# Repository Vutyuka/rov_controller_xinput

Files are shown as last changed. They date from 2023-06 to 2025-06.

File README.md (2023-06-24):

# ROV Controller firmware

ROV Controller firmware, emulating an XBOX gamepad,
using XInput. An underwater casing will be used,
so all buttons are two-state push buttons.
Buttons represent Hall-effect sensors in the hardware.

Basic controller functionality, easy to add and remove buttons:

1. Add/remove pinout definition for pin.
2. Add/remove pin to button_table.
3. Change button_num.

Using Left Joystick with 4 push buttons. 
Joystick position/speed can be toggled by push button.

Any number of discrete speeds can be added to motor_speed_t.

Tested on Pro Micro(has to be flashed as Leonardo).

**To flash:** Press reset just as the IDE shows "Uploading" promt
IT WILL BRICK THE DEVICE IF THIS IS NOT DONE.

For more on XInput: https://github.com/dmadison/ArduinoXInput

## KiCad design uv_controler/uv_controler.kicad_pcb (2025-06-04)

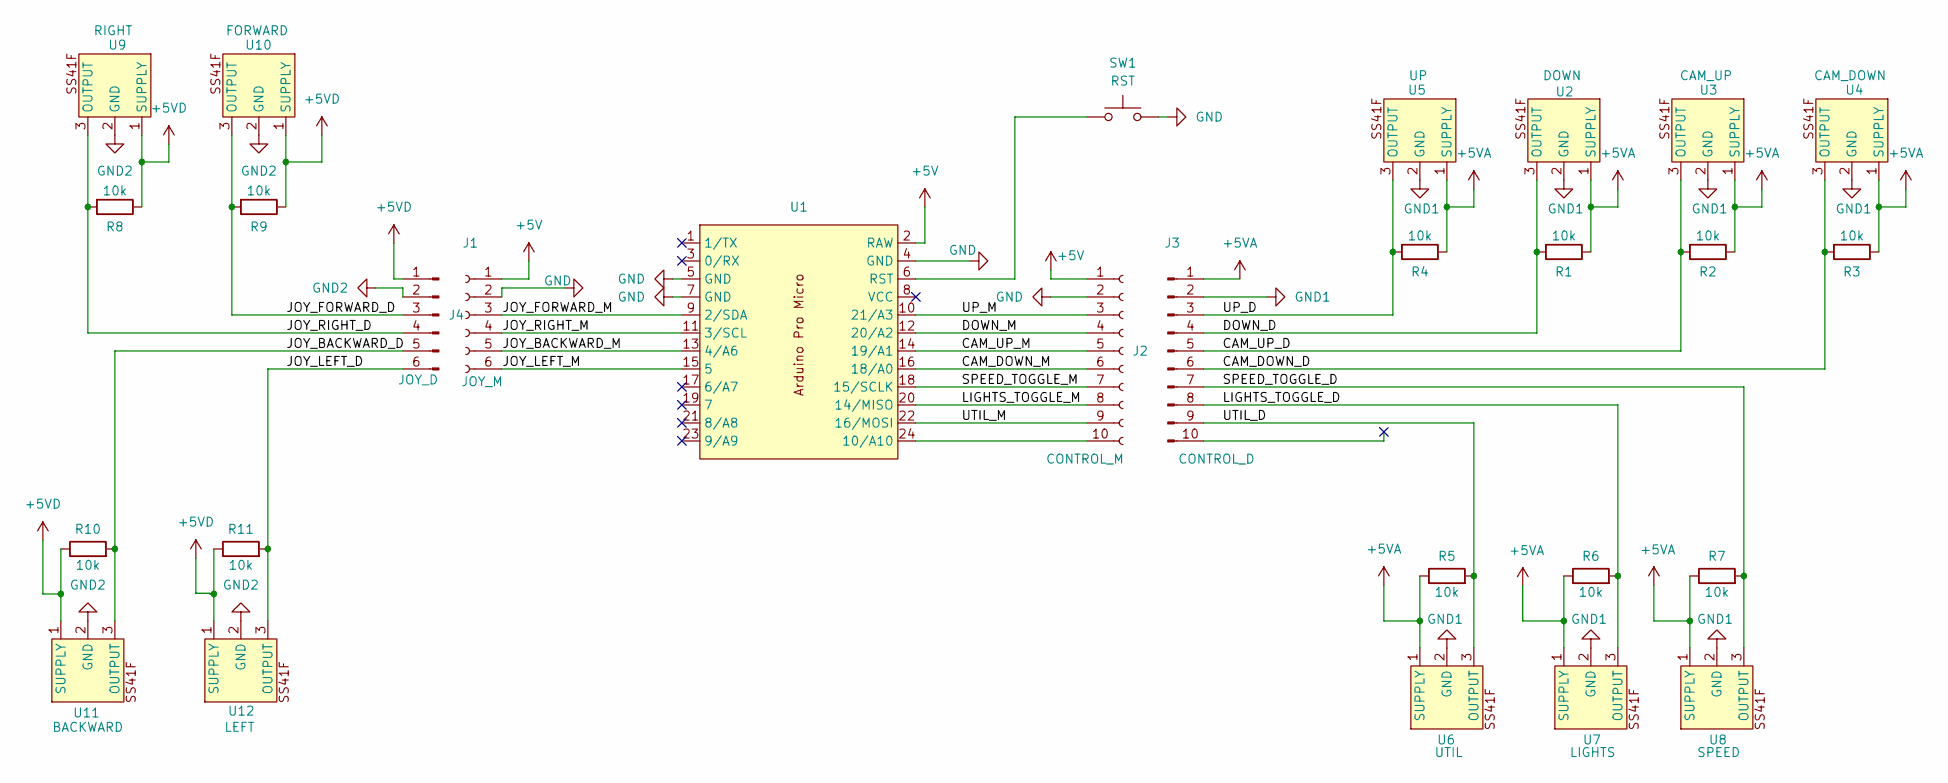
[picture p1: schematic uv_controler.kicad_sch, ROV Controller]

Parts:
J1: JOY_M; PinSocket_1x06_P2.54mm_Vertical
J2: CONTROL_M; PinSocket_1x10_P2.54mm_Vertical
J3: CONTROL_D; PinHeader_1x10_P2.54mm_Vertical
J4: JOY_D; PinHeader_1x06_P2.54mm_Vertical
R1, R2, R3, R4, R5, R6, R7, R8, R9, R10, R11: 10k; R_0603_1608Metric_Pad0.98x0.95mm_HandSolder
SW1: RST; SW_Tactile_SPST_Angled_PTS645Vx31-2LFS
U1: Arduino_Pro_Micro
U2: DOWN; SS41F
U3: CAM_UP; SS41F
U4: CAM_DOWN; SS41F
U5: UP; SS41F
U6: UTIL; SS41F
U7: LIGHTS; SS41F
U8: SPEED; SS41F
U9: RIGHT; SS41F
U10: FORWARD; SS41F
U11: BACKWARD; SS41F
U12: LEFT; SS41F

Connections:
+5V: J1.1, J2.1, U1.2 (RAW)
+5VA: J3.1, R1.1, R2.1, R3.1, R4.1, R5.1, R6.1, R7.1, U2.1 (SUPPLY), U3.1 (SUPPLY), U4.1 (SUPPLY), U5.1 (SUPPLY), U6.1 (SUPPLY), U7.1 (SUPPLY), U8.1 (SUPPLY)
+5VD: J4.1, R8.1, R9.1, R10.1, R11.1, U9.1 (SUPPLY), U10.1 (SUPPLY), U11.1 (SUPPLY), U12.1 (SUPPLY)
/CAM_DOWN_D: J3.6, R3.2, U4.3 (OUTPUT)
/CAM_DOWN_M: J2.6, U1.16 (18/A0)
/CAM_UP_D: J3.5, R2.2, U3.3 (OUTPUT)
/CAM_UP_M: J2.5, U1.14 (19/A1)
/DOWN_D: J3.4, R1.2, U2.3 (OUTPUT)
/DOWN_M: J2.4, U1.12 (20/A2)
/JOY_BACKWARD_D: J4.5, R10.2, U11.3 (OUTPUT)
/JOY_BACKWARD_M: J1.5, U1.13 (4/A6)
/JOY_FORWARD_D: J4.3, R9.2, U10.3 (OUTPUT)
/JOY_FORWARD_M: J1.3, U1.9 (2/SDA)
/JOY_LEFT_D: J4.6, R11.2, U12.3 (OUTPUT)
/JOY_LEFT_M: J1.6, U1.15 (5)
/JOY_RIGHT_D: J4.4, R8.2, U9.3 (OUTPUT)
/JOY_RIGHT_M: J1.4, U1.11 (3/SCL)
/LIGHTS_TOGGLE_D: J3.8, R6.2, U7.3 (OUTPUT)
/LIGHTS_TOGGLE_M: J2.8, U1.20 (14/MISO)
/SPEED_TOGGLE_D: J3.7, R7.2, U8.3 (OUTPUT)
/SPEED_TOGGLE_M: J2.7, U1.18 (15/SCLK)
/UP_D: J3.3, R4.2, U5.3 (OUTPUT)
/UP_M: J2.3, U1.10 (21/A3)
/UTIL_D: J3.9, R5.2, U6.3 (OUTPUT)
/UTIL_M: J2.9, U1.22 (16/MOSI)
GND: J1.2, J2.2, SW1.2, U1.4 (GND), U1.5 (GND), U1.7 (GND)
GND1: J3.2, U2.2 (GND), U3.2 (GND), U4.2 (GND), U5.2 (GND), U6.2 (GND), U7.2 (GND), U8.2 (GND)
GND2: J4.2, U9.2 (GND), U10.2 (GND), U11.2 (GND), U12.2 (GND)
unnamed: J2.10, U1.24 (10/A10)
unnamed: SW1.1, U1.6 (RST)

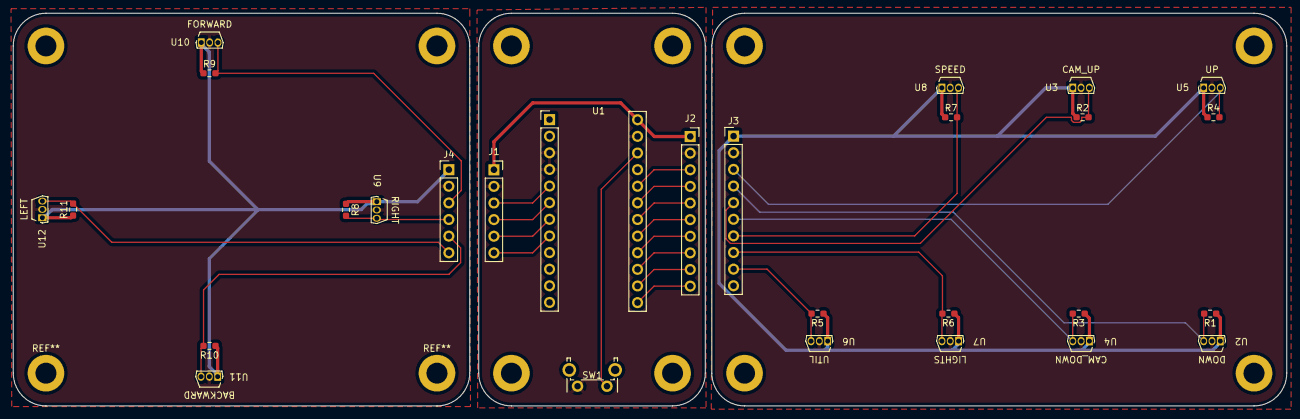
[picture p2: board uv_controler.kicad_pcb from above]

Board: 2 copper layers, 194.6 x 60.0 mm, 28 parts (0 on the bottom side), 30 nets.

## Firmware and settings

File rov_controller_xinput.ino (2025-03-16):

/*
 *  Project     ROV Controller Firmware
 *  @author     Barnabas Miklos
 *  @link       https://github.com/Vutyuka/rov_controller_xinput
 *  @license    GNU - Copyright (c) 2023 Barnabas Miklos
 *

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
 *  Description:  ROV Controller firmware, emulating an XBOX gamepad,
 *                using XInput. An underwater casing will be used,
 *                so all buttons are two-state push buttons.
 *                Buttons represent Hall-effect sensors in the hardware.

 *                Basic controller functionality, easy to add and remove buttons:
 *                1. Add/remove pinout definition for pin.
 *                2. Add/remove pin to button_table.
 *                3. Change button_num.
 *                
 *                Using Left Joystick with 4 push buttons. 
 *                Joystick position/speed can be toggled by push button
 *                Tested on Pro Micro(has to be flashed as Leonardo).
 *
 *                To flash: Press reset just as the IDE shows "Uploading" promt
 *                IT WILL BRICK THE DEVICE IF THIS IS NOT DONE.
 *                For more on XInput: https://github.com/dmadison/ArduinoXInput
 *                             .
 */

#include <XInput.h>

/* Pinout */
#define button_num        11

#define forward_pin       2
#define backward_pin      4
#define right_pin         3
#define left_pin          5

#define up_pin            21
#define down_pin          20

#define speed_toggle_pin  15

#define cam_up_pin        19
#define cam_down_pin      18

#define lights_toggle_pin 14
#define util_toggle_pin   16

#define the_joystick      JOY_LEFT

/* Type definitions */
typedef struct button_t{
  const uint8_t pin;
  const uint8_t ctrl_button;
}button_t;

typedef int motor_speed_t;

enum motor_speed{
  NEUTRAL,
  SLOW,
  FAST,
  SPEED_STATE_NUM ,
};

typedef struct joystick_coords_t{
  int x;
  int y;  
 }joystick_coords_t;

/* Pin function assignment table */

const button_t button_table[button_num]={
  {.pin = forward_pin,        .ctrl_button = JOY_LEFT},
  {.pin = backward_pin,       .ctrl_button = JOY_LEFT},
  {.pin = right_pin,          .ctrl_button = JOY_LEFT},
  {.pin = left_pin,           .ctrl_button = JOY_LEFT},

  {.pin = up_pin,             .ctrl_button = BUTTON_Y},
  {.pin = down_pin,           .ctrl_button = BUTTON_A},

  {.pin = speed_toggle_pin,   .ctrl_button = BUTTON_B},

  {.pin = cam_up_pin,         .ctrl_button = BUTTON_RB},
  {.pin = cam_down_pin,       .ctrl_button = BUTTON_LB},

  {.pin = lights_toggle_pin,  .ctrl_button = BUTTON_R3},
  {.pin = util_toggle_pin,    .ctrl_button = BUTTON_X},
};




static boolean toggle_prev_state;
static motor_speed_t stick_state = SLOW;
static joystick_coords_t joystick_xy = {0,0};

void increase_motor_speed(motor_speed_t * stick_state){
  stick_state[0]=stick_state[0]+1;

  if(stick_state[0] == SPEED_STATE_NUM){
    stick_state[0] = stick_state[0]%SPEED_STATE_NUM + 1; //to skip 0 and SPEED_STATE_NUM
  }
}

void setup() {
  //Every button will be a two-state push button
  //iterating on all the buttons

  // joystick will  be for push buttons
  XInput.setJoystickRange(-(FAST), FAST);
  XInput.setJoystick(the_joystick,joystick_xy.x,joystick_xy.y);
  
  for(int i = 0;i<button_num;i++){
    pinMode(button_table[i].pin,INPUT_PULLUP);
  }

  toggle_prev_state = 0;


	XInput.begin();
  
}

void loop() {
  //zeroing joystick values to be able to use addition at setting
  joystick_xy = {0,0};
  
  for(int i = 0;i<button_num;i++){
    //read every button's state
    bool current_button = !digitalRead(button_table[i].pin);
    //handling the push buttons as a joystick, getting pos from stick_state, set with button
    if(button_table[i].ctrl_button == the_joystick ){
      
      switch(button_table[i].pin){
        case forward_pin:
          joystick_xy.y += stick_state*current_button; // += to handle simultaneous button pushes
          break;
        case backward_pin:
          joystick_xy.y += -stick_state*current_button; // if zero nothing is done
          break;
        case right_pin:
          joystick_xy.x += stick_state*current_button;
          break;
        case left_pin:
          joystick_xy.x += -stick_state*current_button;
          break;
      }
       
     //setting speed state here with toggling button
    }else if(button_table[i].pin == speed_toggle_pin){
     
      
      if(!toggle_prev_state && current_button){ // only toggle from 0->1 change,  on button push
//        static bool toggle_indicator = 0;
//        toggle_indicator = !toggle_indicator;
//        XInput.setButton(button_table[i].ctrl_button,toggle_indicator);

          stick_state = stick_state%(SPEED_STATE_NUM-1) + 1;//cycling through discrete speeds and skipping 0 and SPEED_STATE_NUM
          
      }
      toggle_prev_state = current_button;

    }else{
      XInput.setButton(button_table[i].ctrl_button,current_button);
    }
  }
  //setting joystick after all the buttons states are read
  XInput.setJoystick(the_joystick,joystick_xy.x,joystick_xy.y);
  //send all the button states to the host
  XInput.send();
}

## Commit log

2023-06-18 discrete joystick added, untested probably not working
    [rov_controller_xinput.ino]
2025-03-16 added pcb, mapping added
    [uv_controler.kicad_pcb, uv_controler.kicad_sch]
2025-03-16 arranged pcb roughly
    [uv_controler.kicad_pcb, uv_controler.kicad_sch]
2025-04-26 pcb updates, lot of drc errors remain
    [uv_controler.kicad_pcb, uv_controler.kicad_sch]
2025-06-04 pcb cleanup june 6
    [uv_controler.kicad_pcb, uv_controler.kicad_sch]
2025-06-04 silk fix
    [uv_controler-B_Cu.gbr, uv_controler-B_Mask.gbr, uv_controler-B_Paste.gbr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]

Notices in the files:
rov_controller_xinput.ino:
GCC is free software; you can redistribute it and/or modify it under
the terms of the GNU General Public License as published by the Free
